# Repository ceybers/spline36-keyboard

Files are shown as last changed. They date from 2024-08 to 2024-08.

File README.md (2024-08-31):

# Spline36 Keyboard

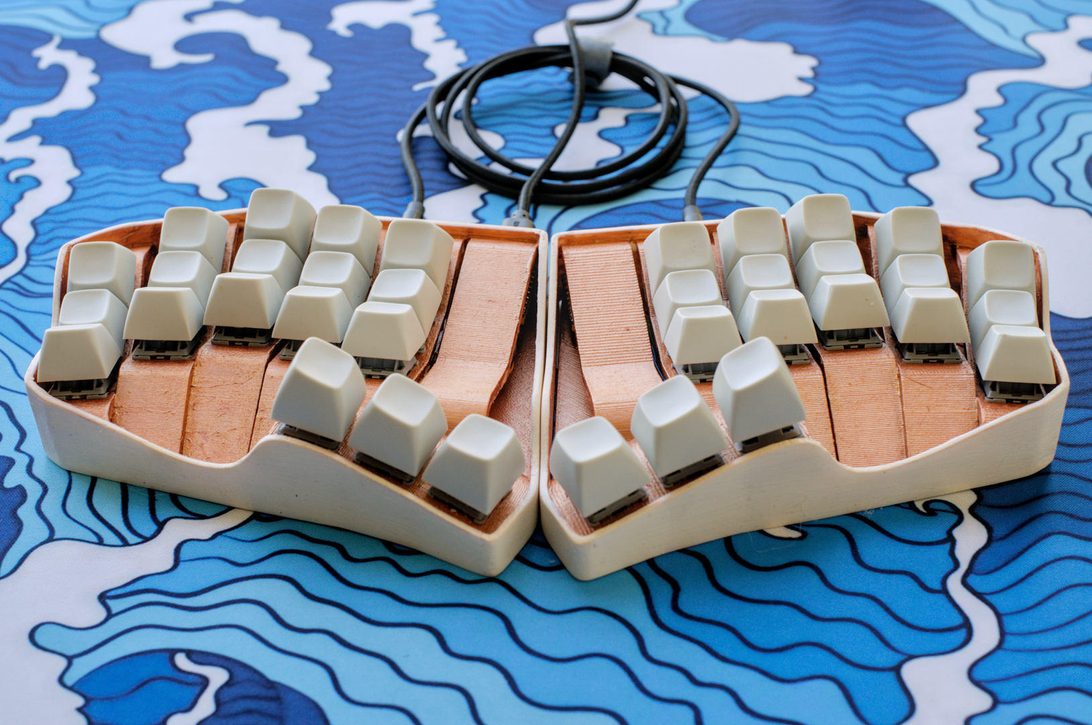
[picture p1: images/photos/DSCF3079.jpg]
Render of the keyboard


## 📻 Project Description

The Spline36 is a 36-key ergonomic split keyboard. 

The columns are staggered, slightly splayed or fanned out, and there is an angle to the top and bottom row to create a key-well effect. Similarly, the thumb cluster is offset and angled to fit under the thumb in a more natural position.

Beneath the plate, all the keys are connected directly (no diodes) to a RP2040 based MCU with a USB-C connector. The two halves are connected via TRRS. The bottom plate is fastened via M2 screws and heat-set inserts. 

[Continue reading...](notes/Design.md)

## 🧰 Features
- 36 keys
- 2× RP2040 w/ USB-C
- TRS split cable
- Powered by QMK with Vial support

## 📚 Read more...
- [Design](notes/Design.md)
- [Construction](notes/Construction.md)
- [Firmware](notes/Firmware.md)
- [Gallery](notes/Gallery.md)

## 🙏 Inspired by...
- [Chortyl by jdart](https://github.com/jdart/chortyl)
- [TBK Mini by BastardKB](https://github.com/Bastardkb/TBK-Mini)

## 📐 References
- [Waveshare RP2040-Zero](https://www.waveshare.com/rp2040-zero.htm)
- [QMK Firmware](https://docs.qmk.fm/)
- [Vial Firmware](https://get.vial.today/)

---

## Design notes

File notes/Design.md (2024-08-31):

# Design

## Spline?

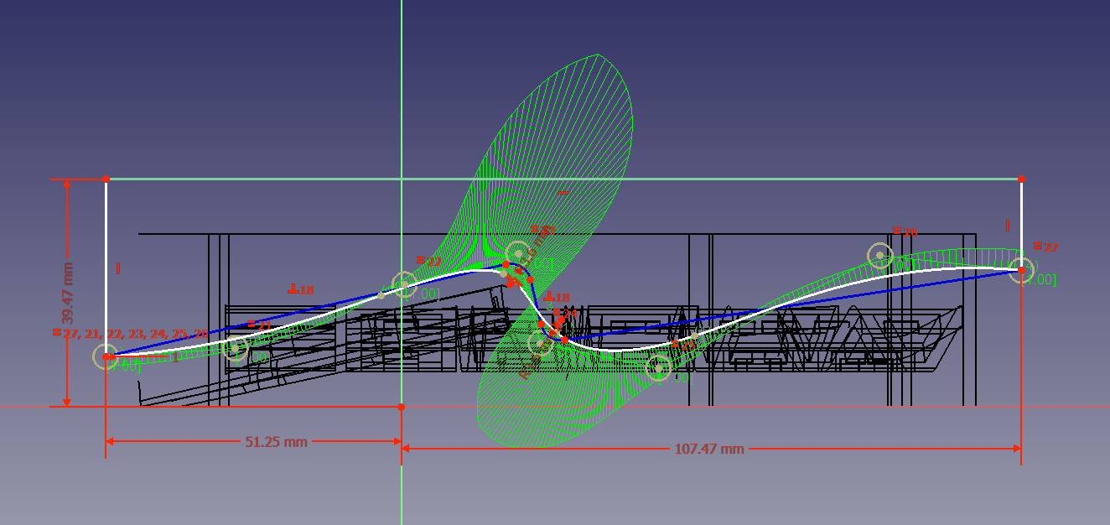
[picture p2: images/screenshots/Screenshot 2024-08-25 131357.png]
Spline on front of case


The name "Spline36" comes from the shapes I used for the shell around the keyboard. I usually stick to orthogonal lines when making keyboards, but this time I decided to take the time and practice working with more organic shapes and slopes in all three dimensions.

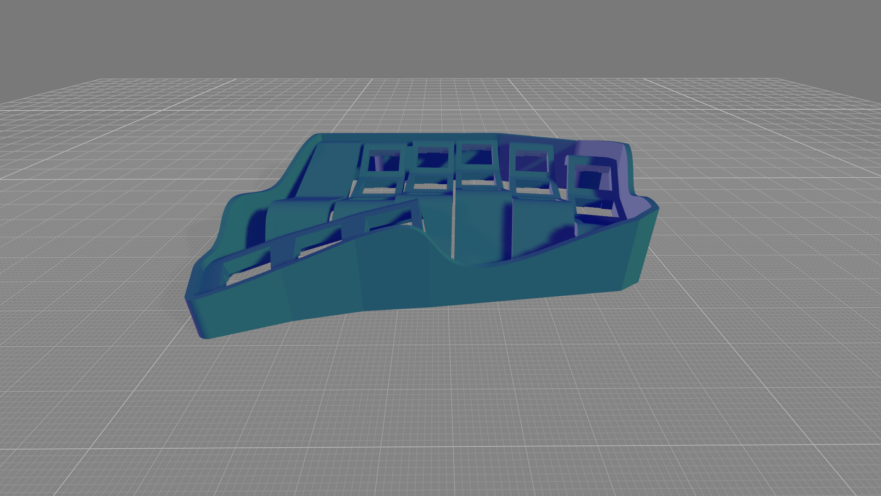
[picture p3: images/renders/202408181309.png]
Render of front of the case


While I could of used a generator like [Ergogen](https://github.com/ergogen/ergogen) or [ryanis.cool's Cosmos](https://ryanis.cool/cosmos/), I stubbornly wanted to place everything myself. All in all, I think it came out really nicely.

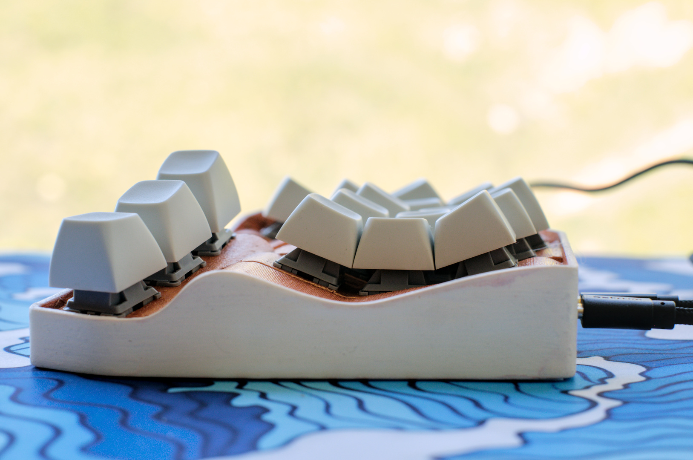
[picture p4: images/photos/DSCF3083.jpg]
Photo of the front of the case


## Inspiration

I have a [TBK Mini](https://github.com/Bastardkb/TBK-Mini) that I use, and I especially like the design Quentin used for the columns, where each key column appears to be a separate part that was rotated and moved around freely, and then held together by an outer frame.  As things go, the TBK didn't fit to my hand exactly, but at the time it didn't bother me enough to build something new.

Next, I saw photos of [jdart's Chortyl](https://github.com/jdart/chortyl) and instantly fell in love with the design. Unfortunately, 34-keys are a *bit* too few for me, and I still wanted something that is custom tailored for my own hands.

## Initial Designs

The previous keyboard I made was my [Shifty Split](https://github.com/ceybers/shifty-split-keyboard), and there were a few changes I wanted to make. The thumb cluster needed to be moved further inwards, the column stagger was nowhere near aggressive enough for my pinkies, I wanted to try out some splay/fanning, and the experiment of the outer column arrow clusters didn't work out as well as I had hoped.

Initially I started on just making these changes, but I still wanted to make something with a key-well, where the top and bottom rows are angled like the examples I linked above. This of course meant starting an entirely new model from scratch.

## First Revision

The first revision of the Spline had a 6th column with a single vertical 2u key. This doubled as being space to place the MCU and TRRS jack on the underside of the empty space above the 2u key.

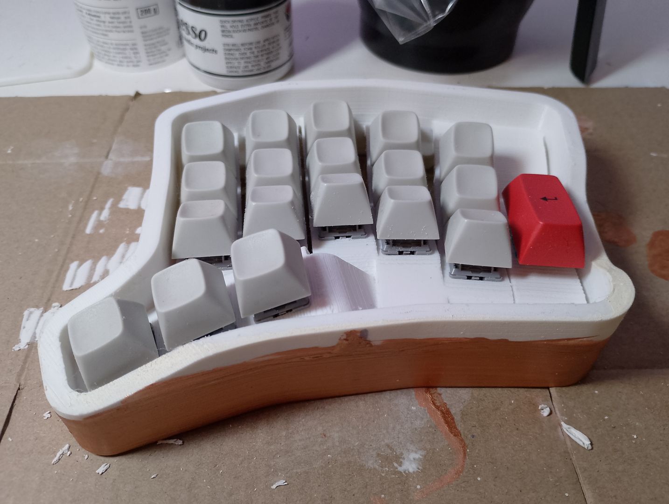
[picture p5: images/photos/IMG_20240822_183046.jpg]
Photo of the first prototype


I am a firm believer in vertical 2u keys in monoblock keyboards, as I can instinctively hit the numpad Enter key with my right hand while using the mouse. I also find it convenient to be able to just hit the rightmost key with my thumb when my hands are off the keyboard.

Of course, most of this doesn't really apply when using split keyboards, as the mouse or trackball usually goes *in-between* the halves. 

Having outer keys could still work for hands-off thumb presses, but they don't really fit in with how I use the keyboard when actively typing. I definitely didn't want to use them with my pinkies either - I'm trying to place more of the keyboard work on my thumbs, index and middle fingers.

## Second Revision

I decided to move the MCU to the traditional location for split keyboards: inwards in the column to the side of the index finger key column, above the thumb keys. 

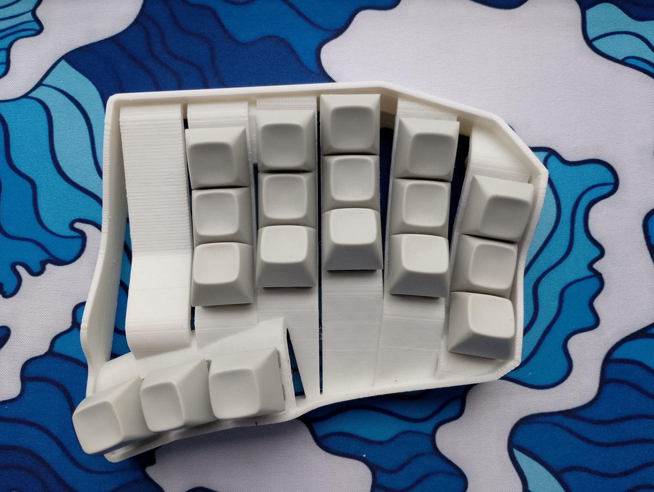
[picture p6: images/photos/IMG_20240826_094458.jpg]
Photo of second revision before painting


It turns out that the columns I was using for the keys is not only just the right width, it is also high enough off the floor that the MCU can fit beneath it, even with vertical header pins soldered on.

I also reduced the wall thickness from an overly chunky 5mm to a more reasonable 3.6mm. Adding some more angle to the different columns made the case feel more open, especially with the way the outer shell folds around the inner column, which shows off the bottom plate nicely.

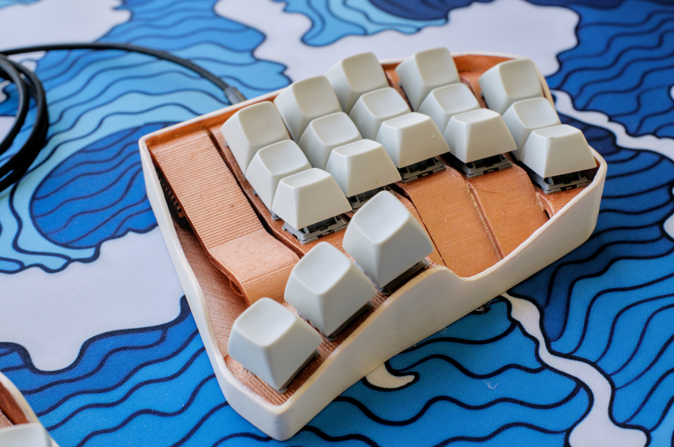
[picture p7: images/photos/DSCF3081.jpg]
Photo of the top/front of the keyboard


---

⏯️ *Design* | ⏩ [Construction](Construction.md) | ⏏️ [README.md](../README.md)

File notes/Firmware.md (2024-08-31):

# Firmware

## QMK and Vial
For the firmware, I used QMK. Once the QMK firmware is working OK, I then port my config to Vial and compile a QMK/Vial firmware.

For some reason I had a lot of issues this time. Despite things being almost identical to my previous split keyboard build, I couldn't get the keyboard halves to work together.

It took more time than I'd like to admit, but eventually I got it to work. In the end, I used the pin method to determine handedness, where you wire a pin to HIGH (3v3) on one of the halves to identify it as the master board, and the second half will without this pin wired HIGH will then default to slave.

Some advice is to use a multimeter to make sure the slave board is receiving power from the master board across whichever split link you use. If your MCU has an onboard LED, configure your firmware to turn it on at boot. This will let you easily notice if wires come loose while testing. 

If you haven't used Boot Magic before, set it up. This allows you to hold a key (e.g., top-left key) while plugging the keyboard in to boot into bootloader mode. This is usually much more convenient than trying to hold the BOOTSEL button on a MCU. And if you don't have one, consider a small USB2 hub that has on/off buttons for each port, which is much more convenient than physically removing and reinserting plugs.

Lastly, ensure the pin you are using is compatible with your protocol method (e.g., USART TX). On newer boards like the RP2040 this is not as much of a restriction, but while testing you want to remove as many variables as possible.

## Notes
- For my base layout, I use [Colemak-DH](https://colemakmods.github.io/mod-dh/).
- For split keyboards in particular, I like to start with Manna Harbour's [Miryoku layout](https://github.com/manna-harbour/miryoku).
- If you opt to use Home Row Mods (and you should definitely give them a try, at least once), then [precondition's definitive article on Home Row Mods](https://precondition.github.io/home-row-mods) is a must read.
- If you end up accidentally triggering unwanted modifiers on the same hand, have a look at Manna Harbour's [Bilateral Combinations](https://github.com/manna-harbour/qmk_firmware/blob/bilateral-combinations/docs/tap_hold.md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).
- The next thing I'd suggest having a look at is Pascal Getreuer's Achordion library: [Achordion: Customizing the tap-hold decision](https://getreuer.info/posts/keyboards/achordion/index.html).
---

⏪ [Construction](Construction.md) | ⏯️ *Firmware* | ⏩ [Gallery](Gallery.md) | ⏏️ [README.md](../README.md)

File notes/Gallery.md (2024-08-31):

# Gallery

## FreeCAD Screenshots
Screenshot of the spline on the front of the case

## Renders
Render of the front of the case
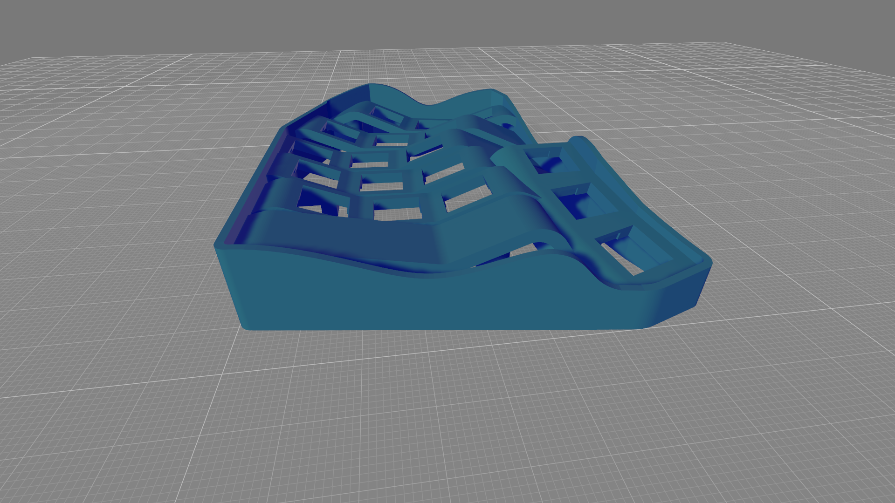
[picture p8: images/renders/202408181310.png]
Render of the inwards side of the case

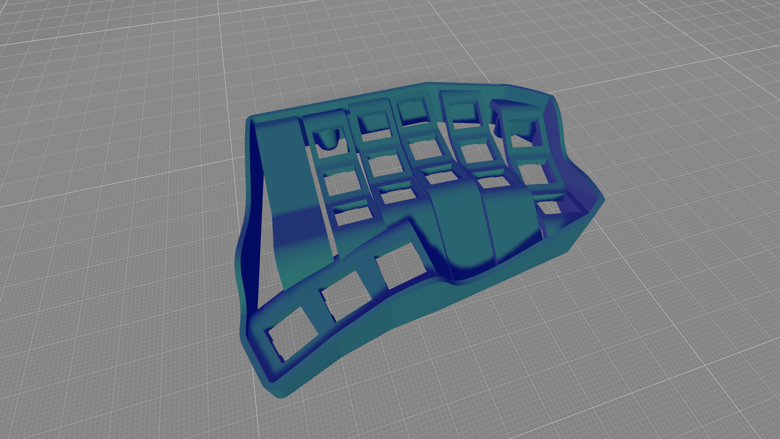
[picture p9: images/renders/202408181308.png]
Top-left render of the case


## Photos
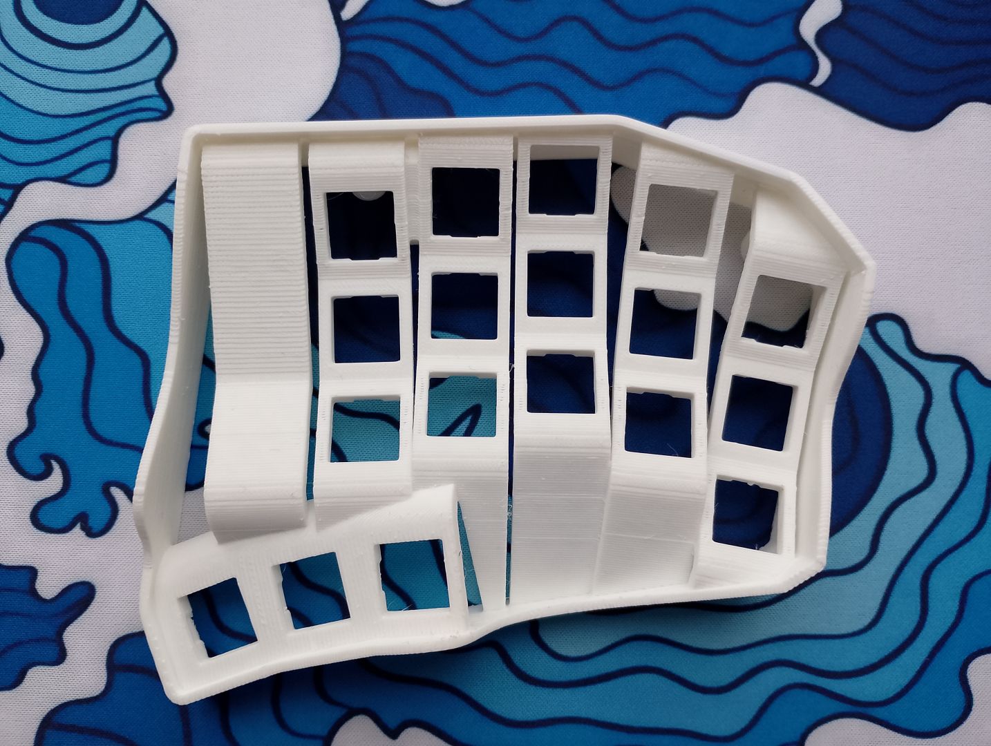
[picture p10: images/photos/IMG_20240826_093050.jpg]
Photo of empty keyboard shell

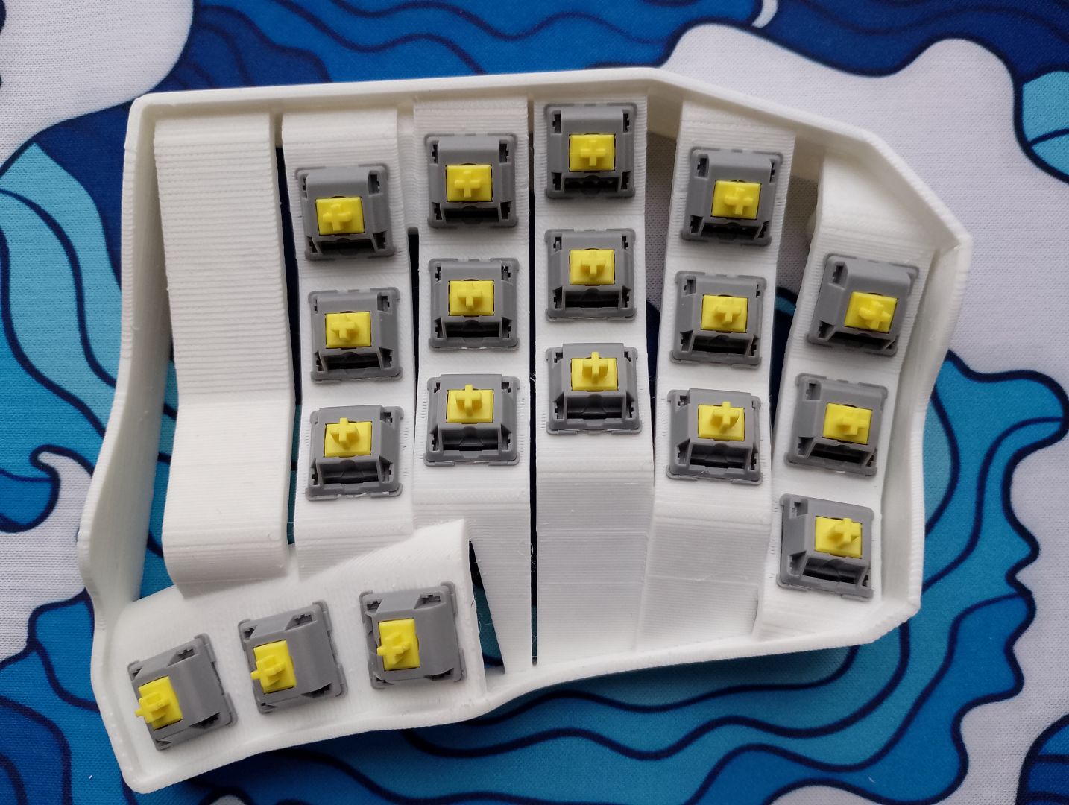
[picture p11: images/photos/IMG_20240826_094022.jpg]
Photo of keyboard with switches
 
Photo of keyboard with switches and keycaps 
Photo of painted keyboard with switches and keycaps 
Photo of both keyboard halves 

---

⏪ [Firmware](Firmware.md) | ⏯️ *Gallery* | ⏏️[README.md](../README.md)

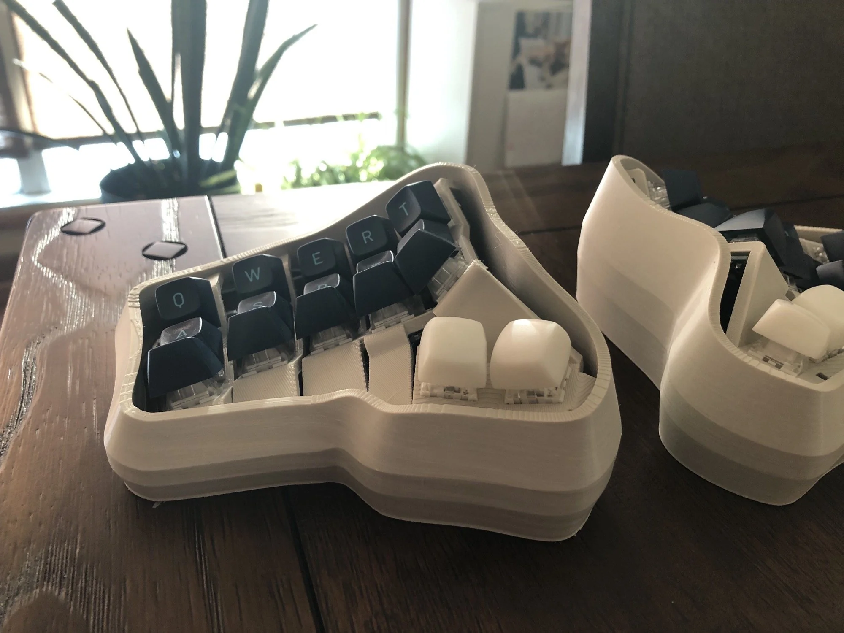
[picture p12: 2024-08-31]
images/inspiration/chortyl-by-jdart.webp

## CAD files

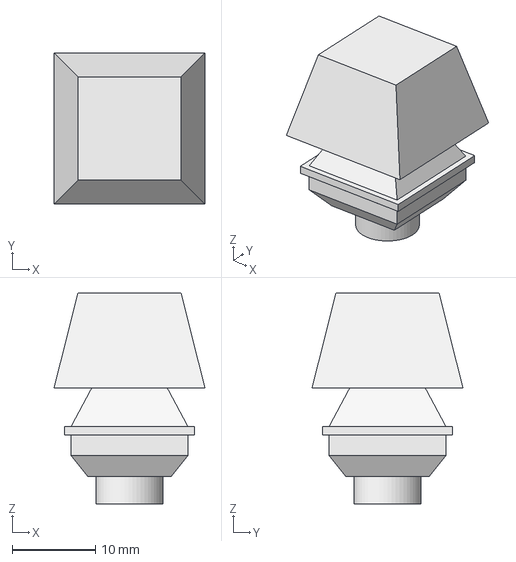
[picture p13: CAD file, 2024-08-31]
components/MX_Switches.FCStd
18.1 x 18.1 x 25.3 mm

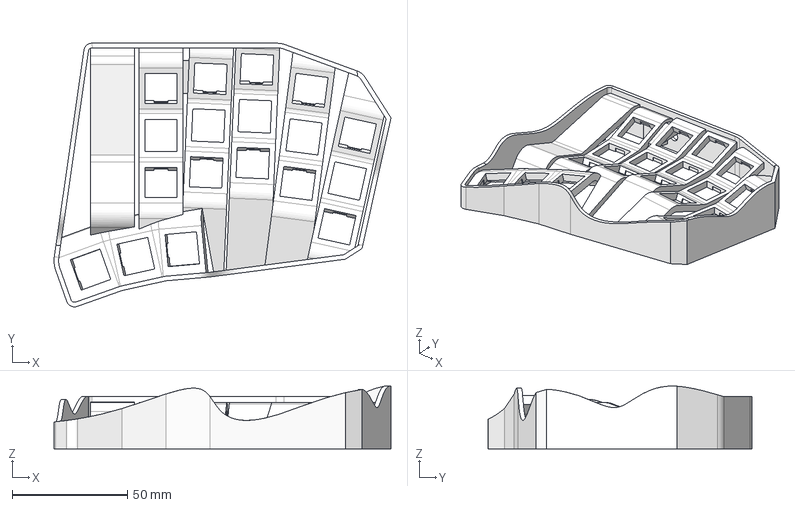
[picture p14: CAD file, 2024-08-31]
freecad/KeyColumnArray2.FCStd
146.0 x 114.3 x 27.3 mm

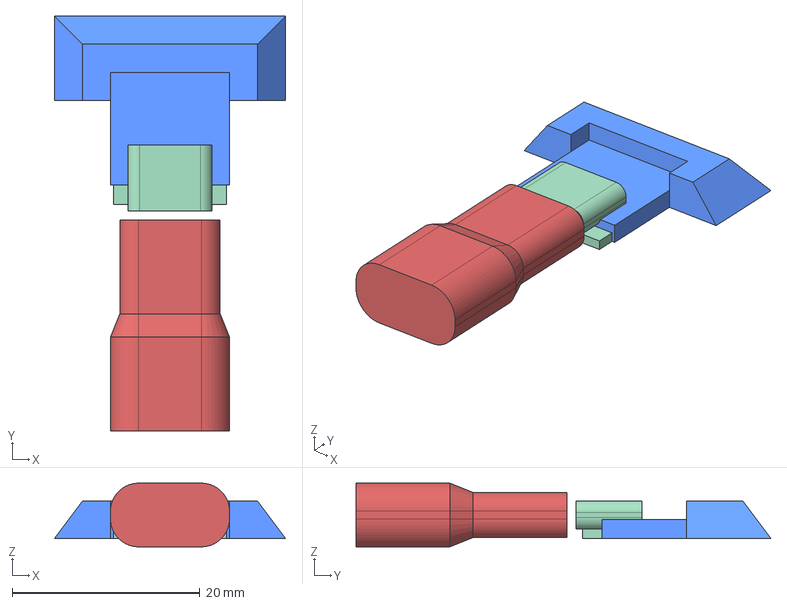
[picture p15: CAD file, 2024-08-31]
components/USBC-Breakout.FCStd
24.7 x 44.2 x 6.80 mm
USBCBreakoutNice
StopperAdd
StopperAddNice
StopperCutNice

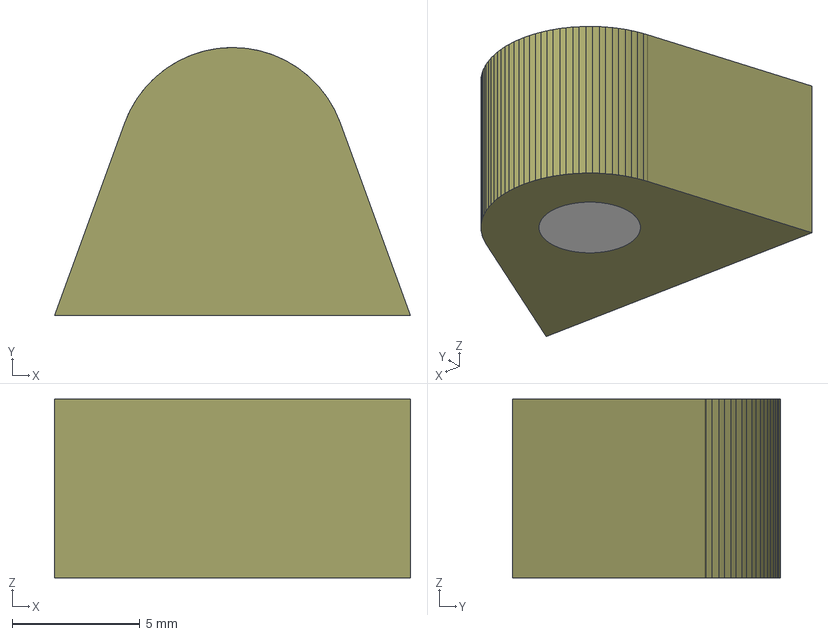
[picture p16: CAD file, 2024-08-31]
freecad/HeatsetInserts.FCStd
13.9 x 10.5 x 7.00 mm
AddHeatset
HeatsetPartNice
HeatsetPartRoundNice

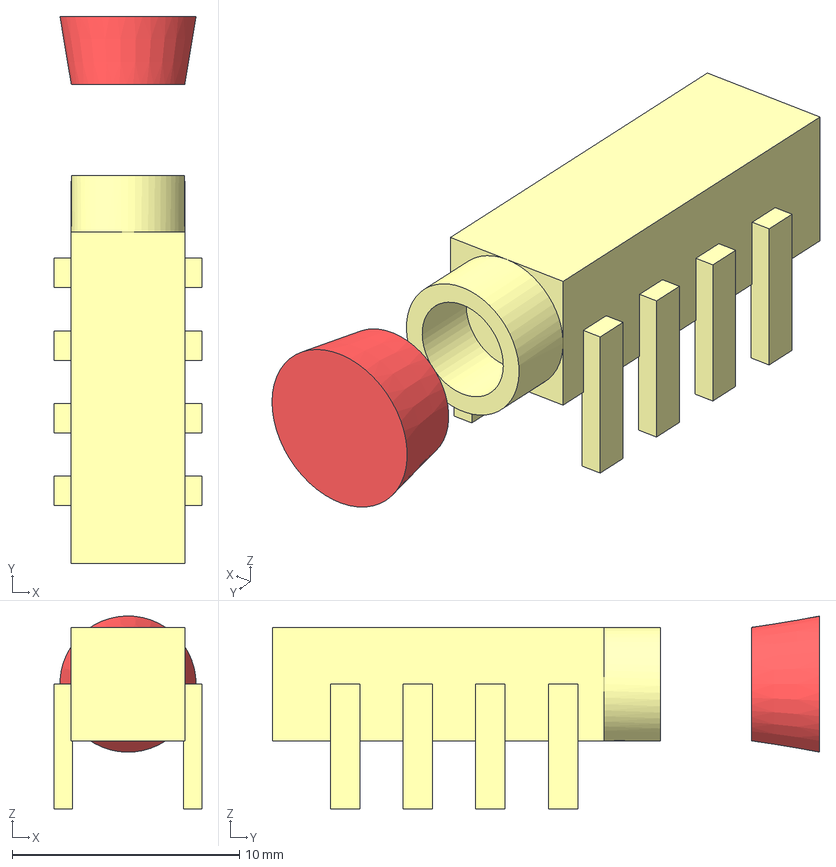
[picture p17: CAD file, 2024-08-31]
components/PJ-313B__JACK35F-4P-PCB.FCStd
6.50 x 24.1 x 8.50 mm
TRRS-CutterN
TRRS-PJ-313BN

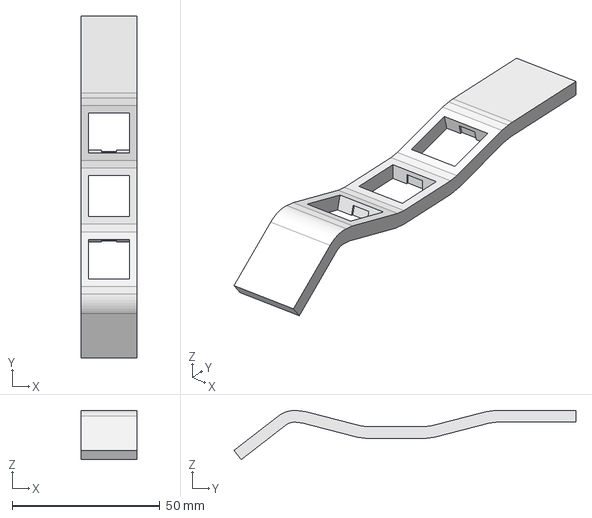
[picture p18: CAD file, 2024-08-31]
freecad/KeyColumn.FCStd
19.0 x 115.7 x 16.7 mm

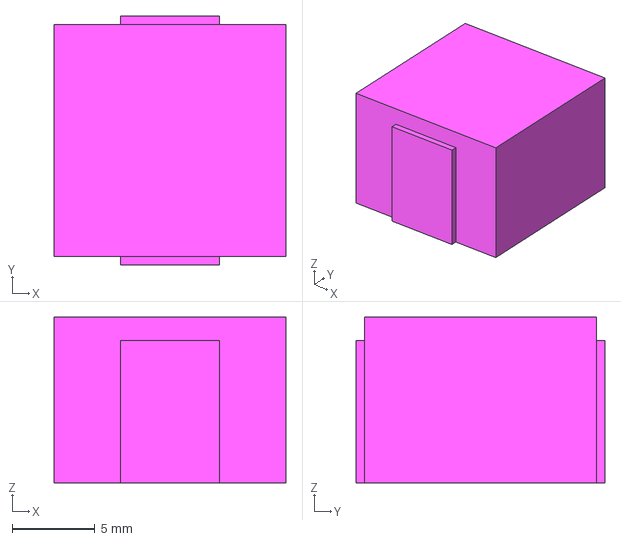
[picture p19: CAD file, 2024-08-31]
components/MX-Latch-Subtractor2.FCStd
14.0 x 15.0 x 10.0 mm

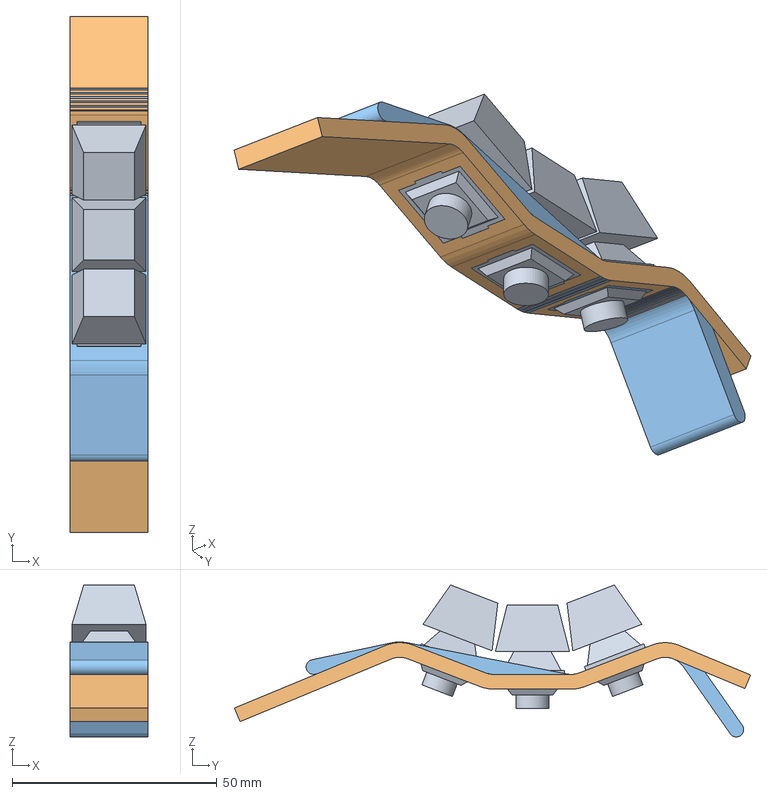
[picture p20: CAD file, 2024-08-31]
freecad/KeyColumn2.FCStd
19.0 x 126.2 x 37.2 mm
KeyColumnCapsN
KeyColumnCutN
KeyColumnBlankN

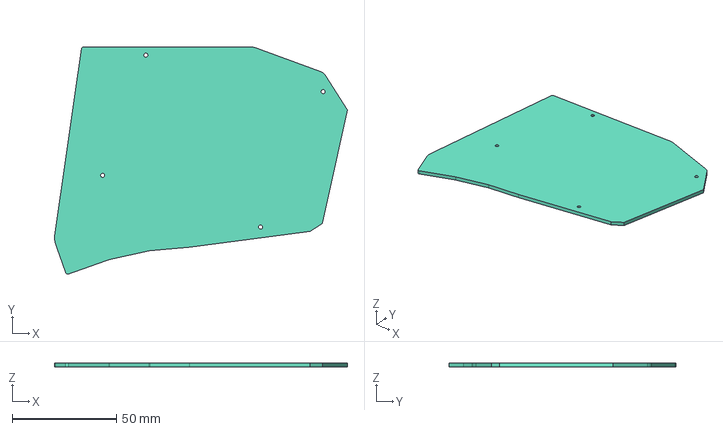
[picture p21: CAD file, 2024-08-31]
freecad/PlateBottom.FCStd
140.8 x 109.3 x 2.00 mm

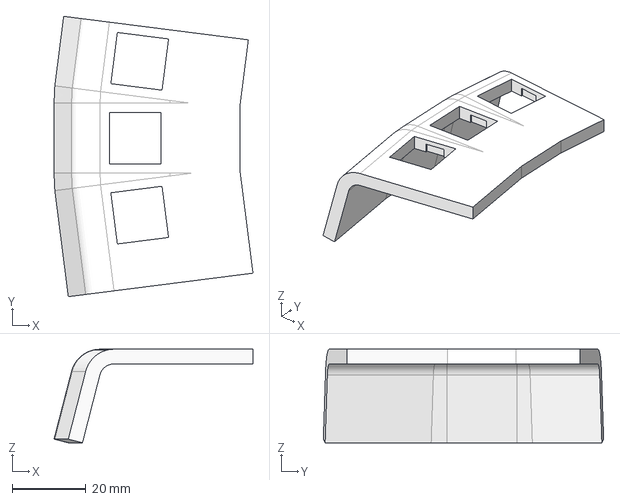
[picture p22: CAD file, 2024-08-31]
freecad/KeyRowThumb2.FCStd
54.0 x 76.0 x 25.4 mm

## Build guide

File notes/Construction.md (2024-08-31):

# Construction

## 🛒 Bill of Materials (BOM)

| Item | Size | Qty | 
| ---- | ---- | --- |
| Waveshare RP2040-Zero | N/A | 2 |
| MX Switches | N/A | 36 |
| Heat Set Inserts | M2 ø3.5×5mm | 10 | 
| Screws, Countersunk | M2 | 10 |
| TRRS Jacks | PJ-313B | 2 |
| TRRS Cable | M-M | 1 |
| Wire | 30AWG | N/A |
| 3D printed shell | N/A | 4 pcs |

## Tolerances
**IMPORTANT**: The current FreeCAD files and .stl models have an issue where the clearance between the keys is too tight, and keycaps will likely bind and chafe against each other:

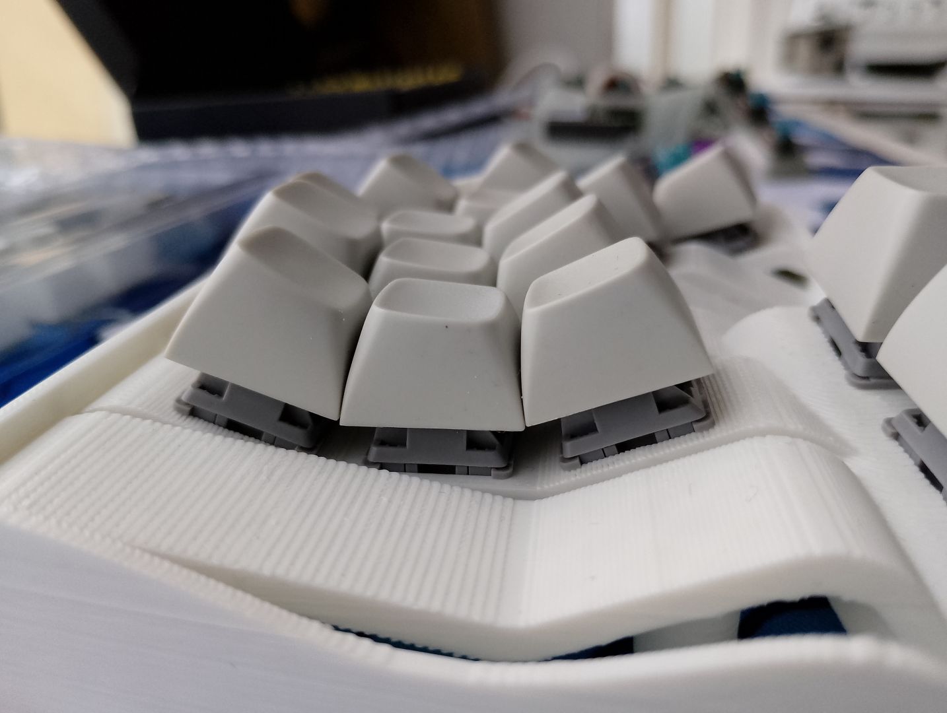
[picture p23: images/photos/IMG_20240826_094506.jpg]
Profile view of keyboard showing keycap tolerances


This is not enough to cause accidental actuation of adjacent keys. I'm still experimenting to see how bad the feel is in practice.

## Wiring
With only 18 switches per side and no accessories like OLEDs or LEDs, there are enough GPIO pins to wire each switch directly to the MCU. 

This means each pin has one wire going to a GPIO pin, and a second wire that goes to ground. To manage the ground wires, I used a spare piece of header pins with at least 7 pins. On the short side I shorted all the pins together and wired these to the MCU's GND pin. The long sides were connected to a common wire on each key column, and the 7th pin provided a GND for the TRS jack used to connect the split halves.

## Parts
The MCU fitted perfectly: both the USB jack fits in the hole in the shell, a USB cable can fit through and connect to it, and the MCU itself fits flush against stopper. 

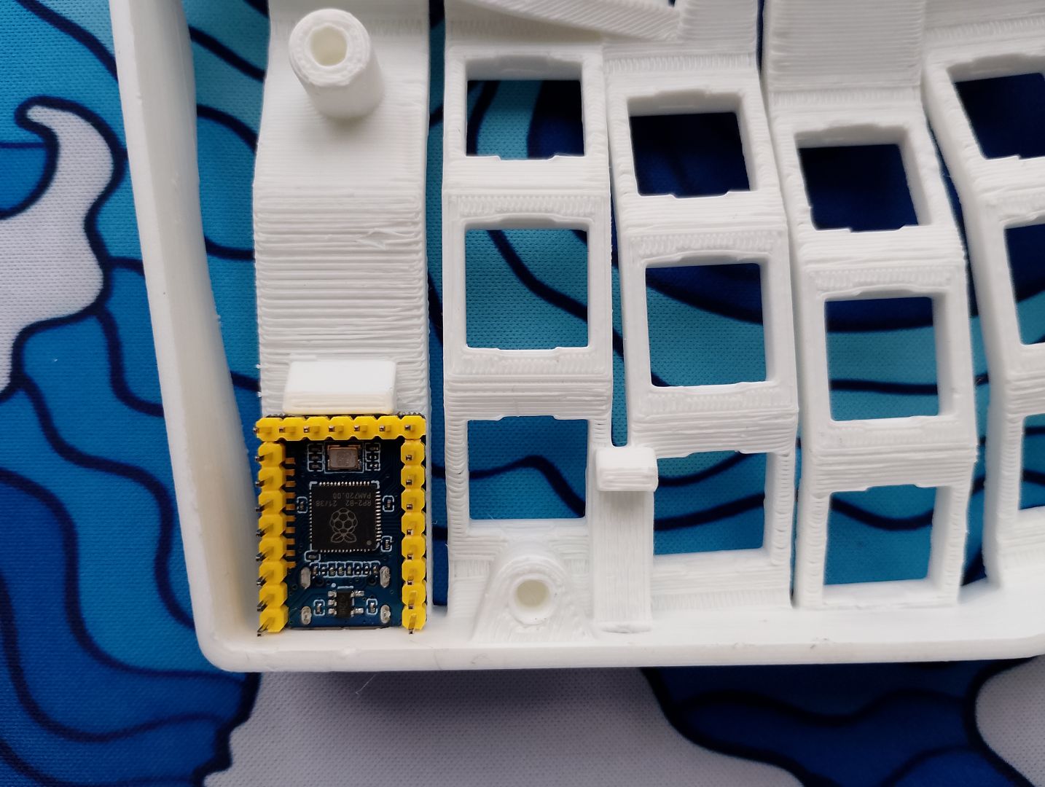
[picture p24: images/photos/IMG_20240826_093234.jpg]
Closeup of MCU from above


The purpose of this stopper is to prevent any lateral movement when inserting the USB cable. It prevents the MCU from being pushed in the direction you are pushing the cable and accidentally being dislodged.

Unfortunately, the dimensions for the TRRS jack were too tight. Coincidentally, while building the keyboard, I realised I only have *TRS* cables and no *TRRS* cables. I changed to TRS jacks instead, which are a fair bit shorter and can thus fit in easily.

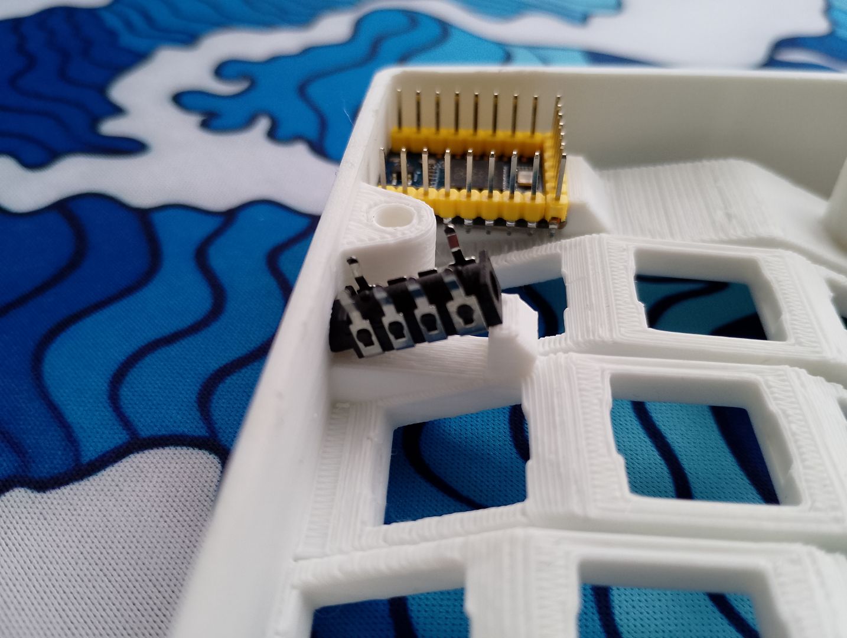
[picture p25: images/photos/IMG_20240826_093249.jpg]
MCU and TRRS Jack


The gap between the new TRS jack and the stopper can be filled with hot glue - just seal off the hole on the back of the TRS jack first with something like insulation tape to prevent ingress of the glue. Again, this is so that when inserting a cable, the stopper prevents the jack from sheared off whatever glue might be holding it down.

## Heat-set Inserts
I settled for only 4× M2 screws to hold the bottom plate in place, and it is working perfectly fine. M2 means smaller heat-set inserts, which means whichever part you place them in needs less wall thickness to absorb extra heat when melting them in.

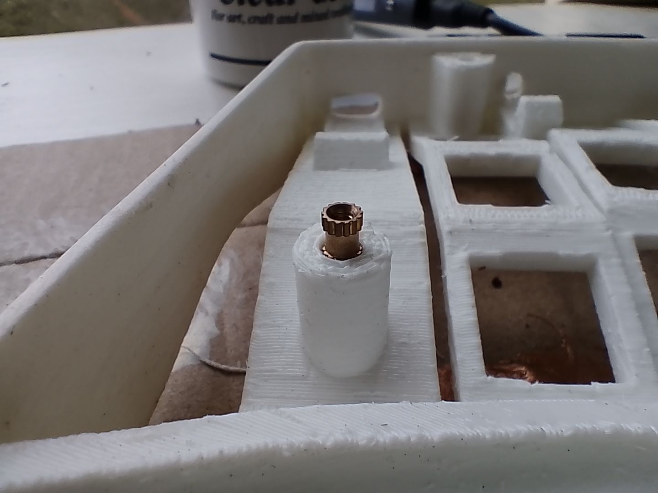
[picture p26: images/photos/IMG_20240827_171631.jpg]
Closeup of heat-set insert before melting it into place


When designing the holes to insert the heat-sets, remember to taper the entrance to help align them. If you have a craft knife set, a straight chisel tip blade is useful for making sure it sets in place level.

Don't forget to apply a taper to the plate side as well, so that the heads of your screws sit flush with the surface.

## Sanding and Painting
I had the case printed in PLA with a 0.12mm layer resolution. I was happy with how it came out, but I wanted to add some colour to it.

Photo of unpainted shell

I sanded the outer shell with several different grits (180, 320 and 600 if I recall correctly). I didn't sand the key columns, as the shape was too awkward to get into. Luckily the grain of the print was just how I wanted it.

I then applied several coats of primer to the outer shell. For the bottom plate, I primed the face that would be facing upwards and through the keyboard.

Once the surface was primed, I applied several coats of acrylic paint. I should have thinned the paint a bit more, but I am still happy with how the final result turned out.

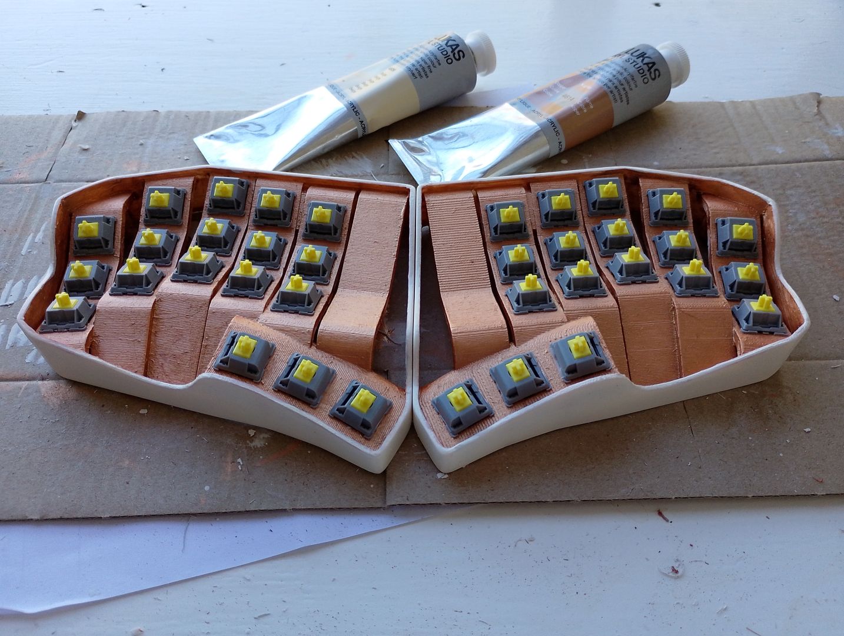
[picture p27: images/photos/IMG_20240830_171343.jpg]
Photo of painting in progress


Some advice: keep any eye out for burrs, dust and hairs before painting *and* while painting. A single strand of hair from your paintbrush can get stuck on without you noticing and blemish the paint job.

---

⏪ [Design](Design.md) | ⏯️ *Construction* | ⏩ [Firmware](Firmware.md) | ⏏️ [README.md](../README.md)
